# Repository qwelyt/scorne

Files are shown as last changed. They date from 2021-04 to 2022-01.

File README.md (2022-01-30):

# scorne
A corne with extra buttons. This is a scorned keyboard.

It is basically a corne, but with three extra buttons. This makes the layout work like a Lets Split (or half of a fourtwelve) but with a thumbcluster lite Corne. It only requires one MCU though.

Parts from https://github.com/MKSwe/OpenSCAD-utils are used in this project.

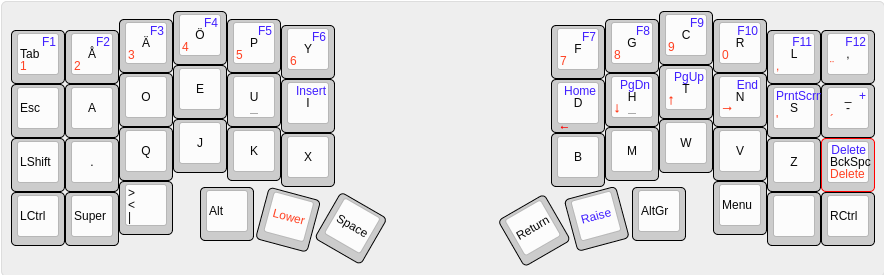
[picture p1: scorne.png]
Scorne keymap with Svorak layout


Scorne build pic
Scorne underside bulid pic

# LICENSE
The firmware is under GNU GPL 3.0.  
The hardware is under CERN-OHL-S.  
See the respective directories for this.

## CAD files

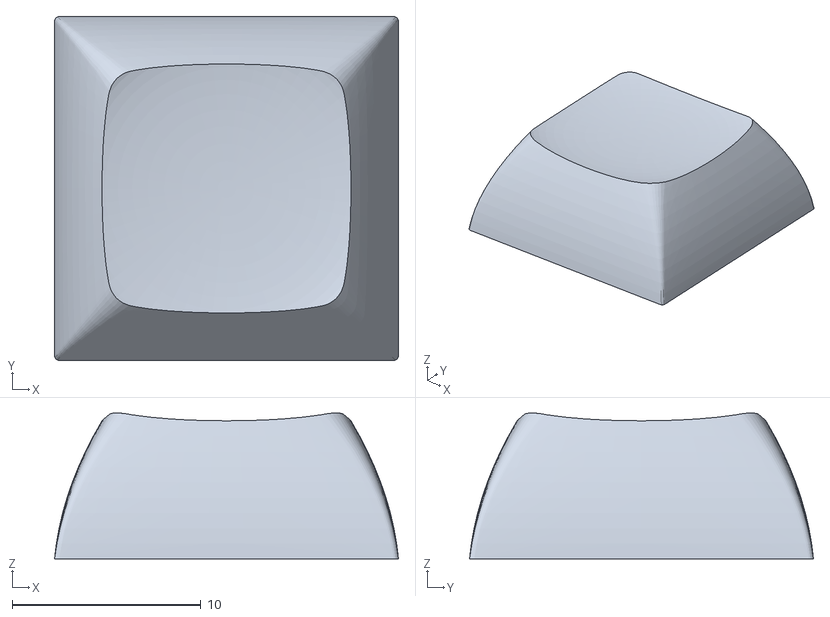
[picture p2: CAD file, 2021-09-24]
hardware/keycap_mx.stl
18.2 x 18.2 x 7.74

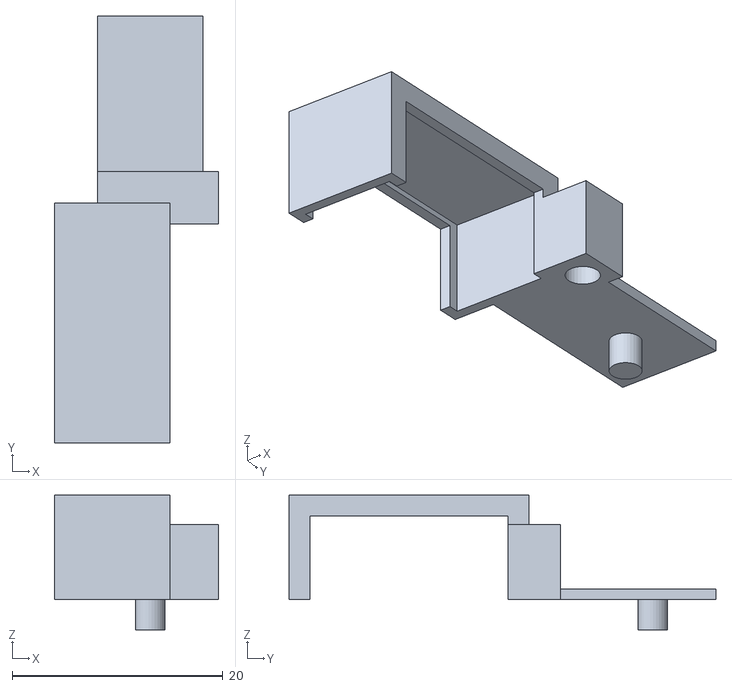
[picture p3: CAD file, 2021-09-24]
hardware/scorne-choc-IDC-right.stl
15.6 x 40.5 x 12.8

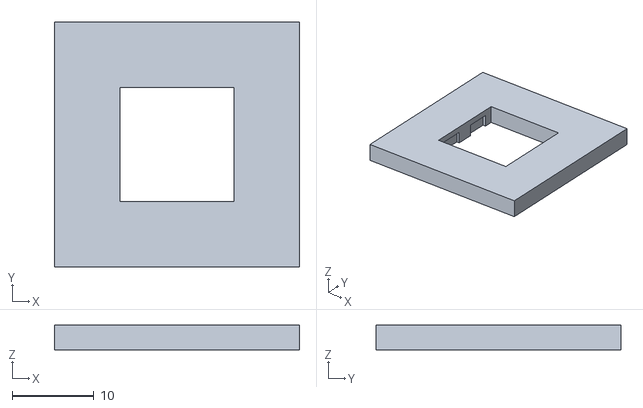
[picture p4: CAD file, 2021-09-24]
hardware/choc-cut-test.stl
30.0 x 30.0 x 3.00

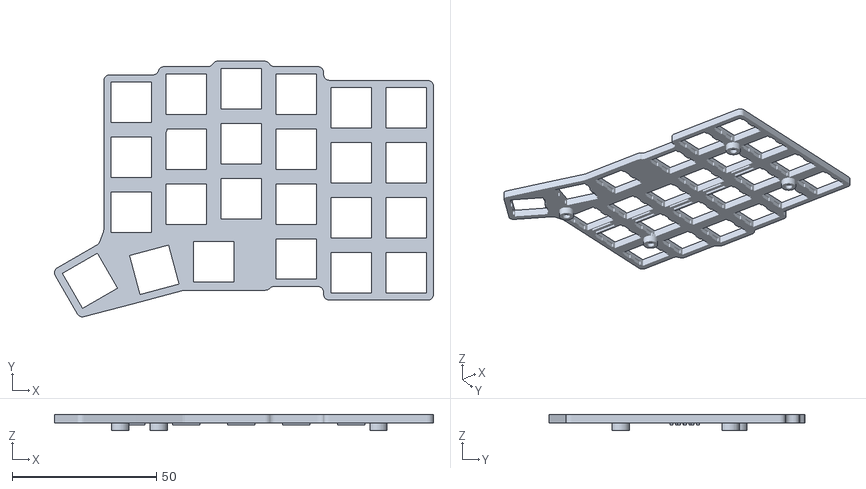
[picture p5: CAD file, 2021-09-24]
hardware/scorne-choc-top-right.stl
131.3 x 88.6 x 5.70

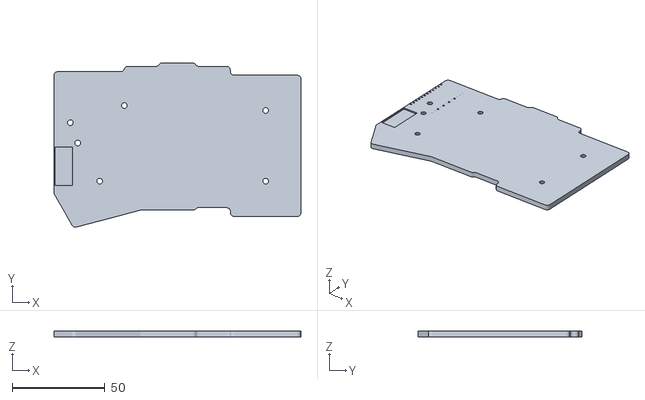
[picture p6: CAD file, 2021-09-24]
hardware/scorne-choc-bottom-right.stl
133.1 x 88.6 x 3.00

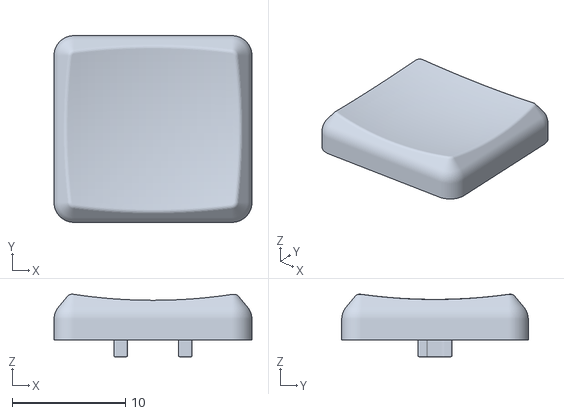
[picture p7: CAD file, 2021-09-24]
hardware/keycap_mbk.stl
17.5 x 16.5 x 5.52

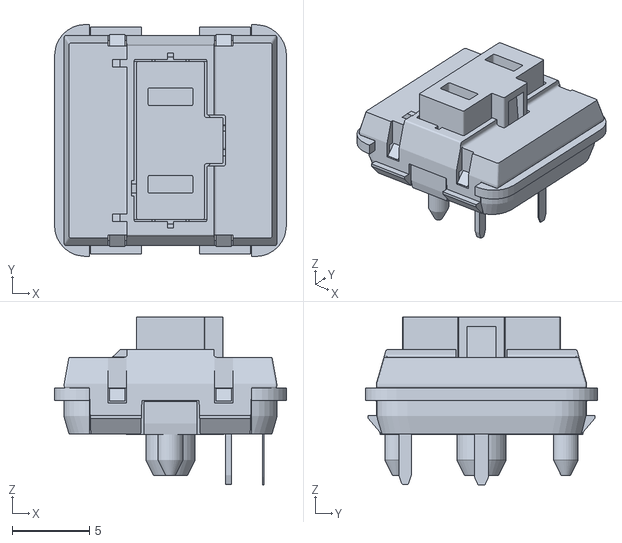
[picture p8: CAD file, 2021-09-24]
hardware/choc.stl
15.0 x 15.0 x 10.9

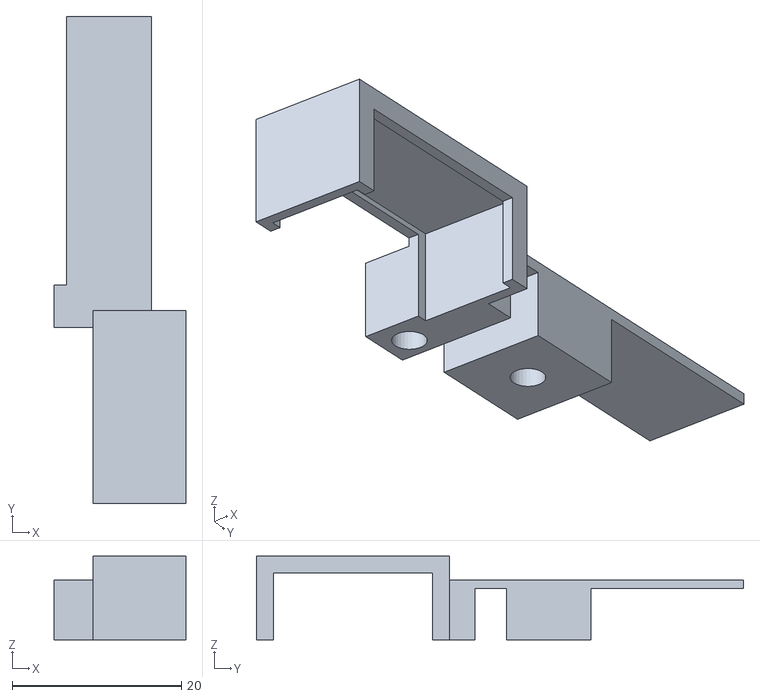
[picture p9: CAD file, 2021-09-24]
hardware/scorne-choc-IDC-left.stl
15.6 x 57.5 x 9.90

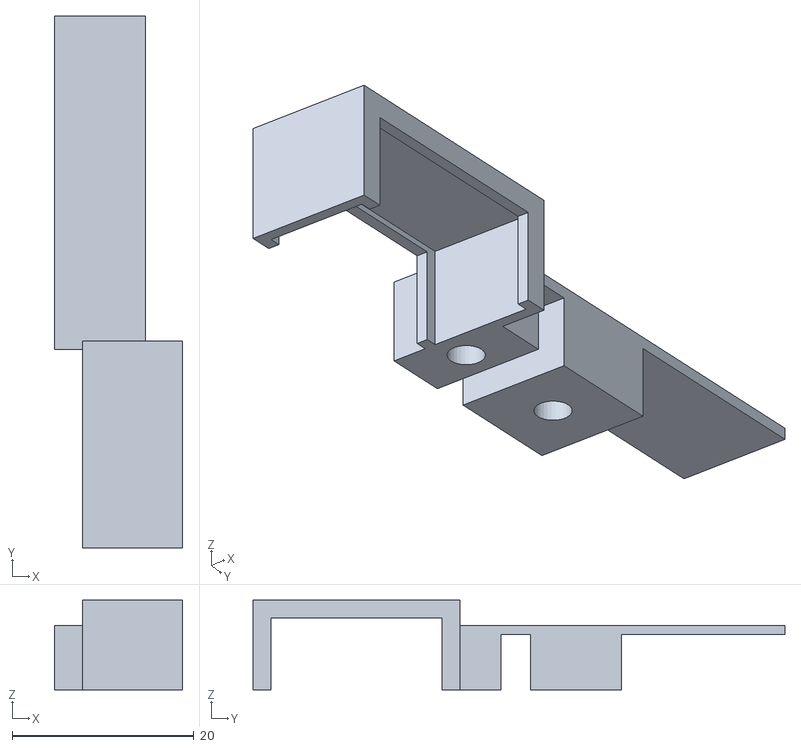
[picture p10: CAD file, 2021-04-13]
hardware/socket-IDC-holder.stl
14.1 x 58.6 x 9.90

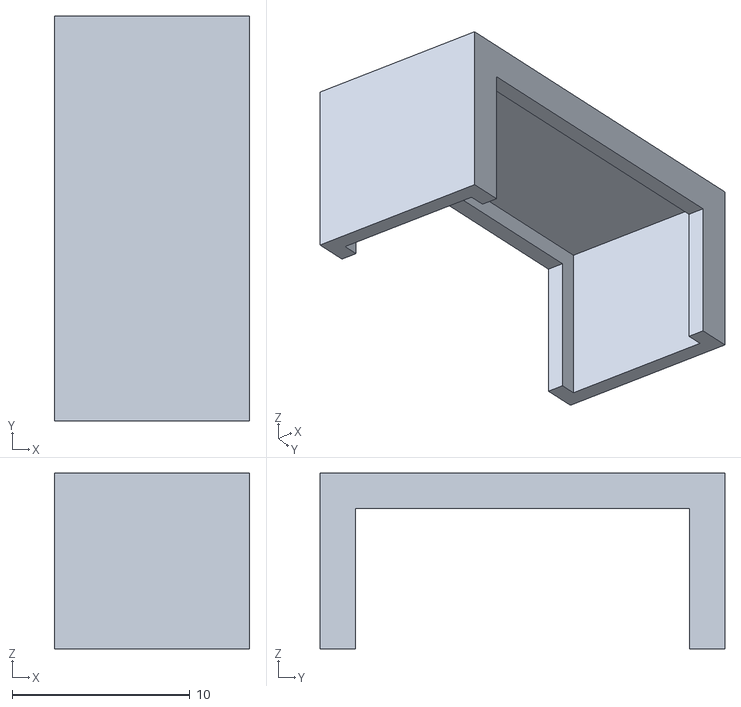
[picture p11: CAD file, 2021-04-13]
hardware/IDC-holder.stl
11.0 x 22.8 x 9.90

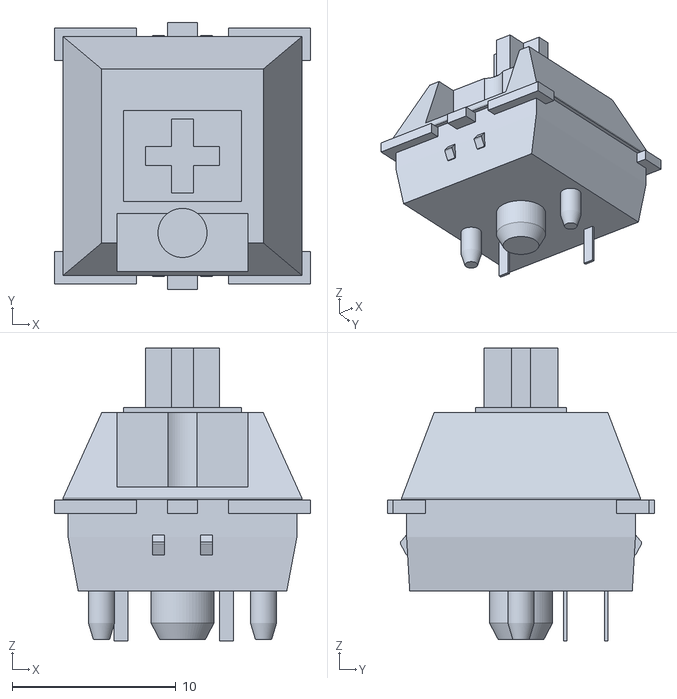
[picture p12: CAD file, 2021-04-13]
hardware/switch_mx.stl
15.6 x 16.3 x 17.9

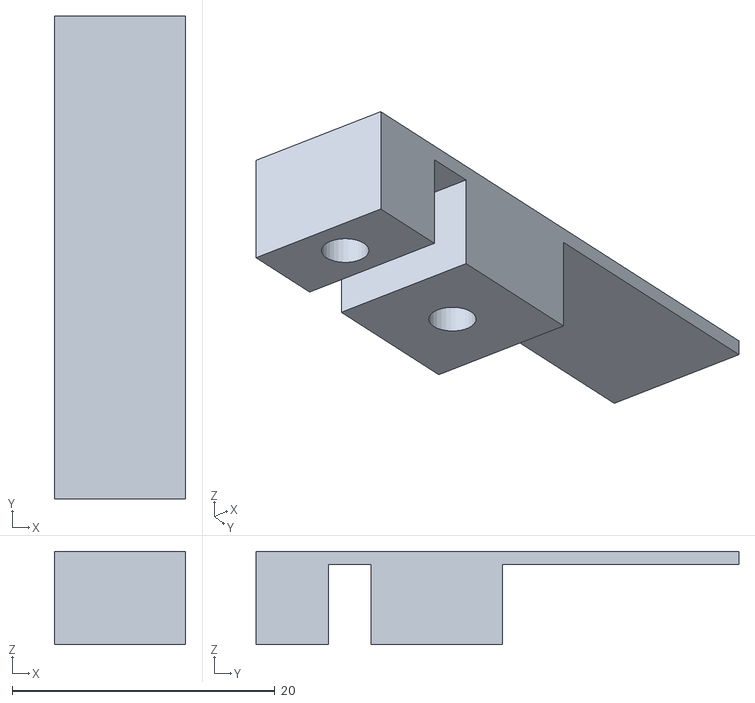
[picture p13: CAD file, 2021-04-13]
hardware/socketHolder.stl
10.00 x 36.8 x 7.10

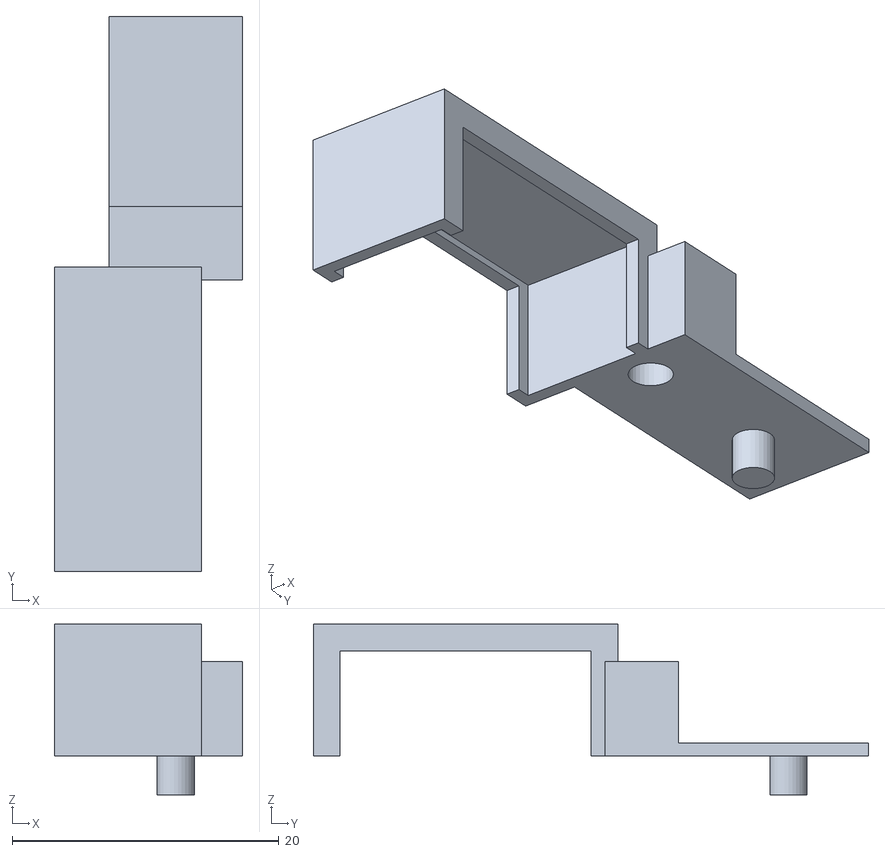
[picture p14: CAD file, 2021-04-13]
hardware/socket-IDC-holder_right.stl
14.1 x 41.6 x 12.8

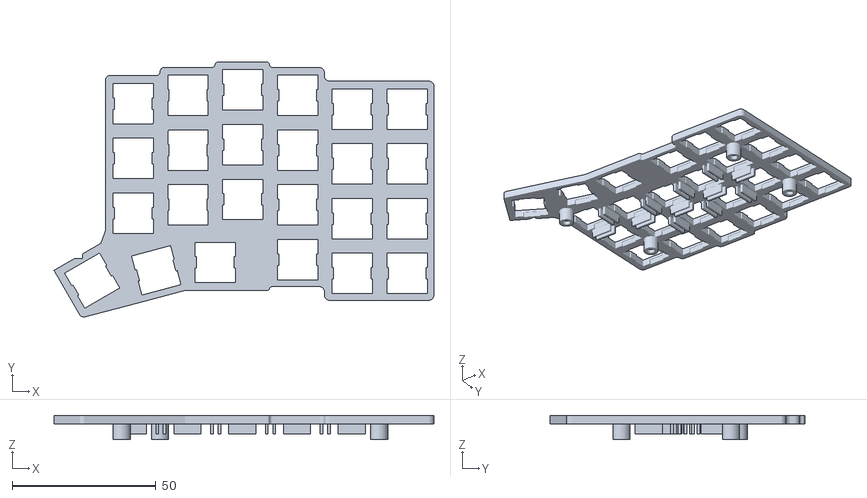
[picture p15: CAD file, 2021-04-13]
hardware/scorne_top_right.stl
132.1 x 88.6 x 8.50

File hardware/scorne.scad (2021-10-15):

showSwitchCut=true;
showSwitch=true;
showKeyCap=false;
showSpaceBox=false;
showScrews=false;
fullboard=false;
space=19.04;
switchType="MX"; // ["MX","choc"]

/*[Cherry MX settings]*/
cherryCutOutSize=13.9954;
cherrySize=14.58;

/*[Keeb]*/
keyCols = 14;
keyRows = 6;
keySpace = space-cherrySize;
edgeSpaceAddition = 3;
edgeSpace = (edgeSpaceAddition*2)-keySpace;
keyZ = -1;

$fn=30;
$fs=0.15;
mSize=3;
moduleZ = 3;
moduleX = size(keyCols);
moduleY = size(keyRows);
keyboardHeight=6.5; // 6.5 for MX, 3.7 for choc

/*[ Printer settings ]*/
showPrintBox=false;
printerSize=[140,140,140];

// mX: h=mX-1, d= X*(1+((1/3)*2))
function mNutH(m) = m-1;
function mNutD(m) = m*(1+((1/3)*2));
function mNutDHole(m) = mNutD(m)+2;
function mScrewheadH(m) = m-1;
function mScrewheadD(m) = m+3; // This is most probably not correct, but works for m3

          
function position(x,y,z) = [space*(x-1), space*(y-1), z];

function size(q) = (keySpace*q)
                        +cherrySize
                        *(q-1)
                        +cherrySize;
function Qsize(q) = (edgeSpace+edgeSpaceAddition)
              +(keySpace*q)
              +cherrySize
              *(q-1)
              +cherrySize;
          



module ooo(r=2){
  offset(r)offset(-r*2)offset(r)children();
}

// ---- Keyboard basics ----
module mxSwitchCut(x=cherryCutOutSize/1.5,y=cherryCutOutSize/1.5,z=0,rotateCap=false){
  capRotation = rotateCap ? 90 : 0;
  d=14.05;
  p=14.58/2+0.3;
  translate([x,y,z]){
    translate([0,0,-3.7])
    rotate([0,0,capRotation]){
      difference(){
        cube([d,d,10], center=true);
        translate([d*0.5,0,0])cube([1,4,12],center=true);
        translate([-d*0.5,0,0])cube([1,4,12],center=true);
      }


      translate([0,-(p-0.6),1.8]) rotate([-10,0,0]) cube([cherryCutOutSize/2,1,1.6],center=true);
      translate([0,-(p-0.469),-1.95]) cube([cherryCutOutSize/2,1,6.099],center=true);

      translate([0,(p-0.6),1.8]) rotate([10,0,0]) cube([cherryCutOutSize/2,1,1.6],center=true);
      translate([0,(p-0.469),-1.95]) cube([cherryCutOutSize/2,1,6.099],center=true);
    }
  }
}

module chocCut(){
  union(){
    cube([14,14,moduleZ*2],center=true);
    translate([0,14/4,-1])cube([15,4,moduleZ],center=true);
    translate([0,-14/4,-1])cube([15,4,moduleZ],center=true);
  }
}


module repeated (yStart, yEnd, xStart, xEnd, yStep=1, xStep=1){
  union(){
    for(y = [yStart:yStep:yEnd]){
      for(x = [xStart:xStep:xEnd]){
        translate(position(x,y,0)) children();
      }
    }
  }
}

module roundedCube(size=[1,1,1], center=false, r=0.5){
  tMin = r;
  txMax = size[0] - r;
  tyMax = size[1] - r;
  tzMax = size[2] - r;
  
  cent = center ? [-(txMax/2+r/2),-(tyMax/2+r/2),-(tzMax/2+r/2)] : [0,0,0];
  
  translate(cent)  
  hull(){
    translate([tMin,tMin,tMin])sphere(r=r);
    translate([tMin,tMin,tzMax])sphere(r=r);
    

    translate([txMax,tMin,tMin])sphere(r=r);
    translate([txMax,tMin,tzMax])sphere(r=r);
    
    
    translate([tMin,tyMax,tMin])sphere(r=r);
    translate([tMin,tyMax,tzMax])sphere(r=r);
    
    translate([txMax,tyMax,tMin])sphere(r=r);
    translate([txMax,tyMax,tzMax])sphere(r=r);
    
  }
}

///////////////////////////////
//  This
//////////////////////////////

module switchCut(){
  if(switchType == "MX"){
    mxSwitchCut();
  } else if(switchType == "choc") {
    translate([9.5,9.5,-moduleZ])chocCut();
  }
}
module switch(){
  if(switchType == "MX"){
    translate([9.5,9.5,15.15])import("switch_mx.stl");
  } else if(switchType == "choc") {
    translate([9.5,9.5,1.3])rotate([0,0,90])import("choc.stl");
  }
}

module keyCap(){
  if(switchType == "MX"){
    translate([9.5,9.5,7])import("keycap_mx.stl");
  } else if(switchType == "choc") {
//    translate([0,0,-2.0])
    translate([9.5,9.5,6.1])rotate([0,0,0])import("keycap_mbk.stl");
  }
}

module mounting(height=10){
  difference(){
    cylinder(d=mSize+3, h=height);
    translate([0,0,-1])cylinder(d=mSize, h=height+2);
  }
}

module keyPlacement(){
    repeated(0,3,1,2)children();
    repeated(0.25,3.25,3,3)children();
    repeated(1.35,3.35,4,4)children();
    repeated(1.25,3.25,5,5)children();
    repeated(1.1,3.1,6,6)children();
    
    translate([size(3.5),-size(0.8),0])children();
    translate([size(4.47),-size(0.8),0])rotate([0,0,-15])children();
    translate([size(5.57),-size(0.83),0])rotate([0,0,-30])children();
//  translate([size(5.57),-size(0.82),0])rotate([0,0,-30])children();
}

module holePlacement(){
  translate([size(1),size(0),0])children();
  translate([size(1),size(2),0])children();
  
//  translate([size(3.3),size(0),0])children();
//  translate([size(2.95),size(2.24),0])children();
  
  translate([size(5.7),size(0),0])children();
  translate([size(5),size(2.14),0])children();
}


module plateNoCuts(){
  union(){
    keyPlacement()square([size(1),size(1)]);
    translate([size(3),-size(0.82),0])square([size(3),size(1.2)]);
    translate([size(5.33),-size(0.82),0])
      rotate([0,0,20])
      square([size(1),size(1)]);
            
    translate([size(5.4005),-size(1.0495),0])
      rotate([0,0,-14.61])
      square([size(1.07),size(1)]);
  }
  
}
module cableGutter(h=10,rotate=false){
  hh = h > 6 ? h-2 : h-0.3; 
  echo(hh);
  if(rotate){
    union()translate([-0.5,-size(0.5),-(h/2)+1])rotate([0,0,90]){
      translate([0,1.1,0])cube([size(0.5),1,hh],center=true);
      translate([0,-1.5,0])cube([size(0.5),1,hh],center=true);
    }
  } else {
    union()translate([size(0.5),0,-(h/2)+1]){
      translate([0,1.1,0])cube([size(0.5),1,hh],center=true);
      translate([0,-1.5,0])cube([size(0.5),1,hh],center=true);
    }
  }
}

module plate(h=10){
  color([0.7,1,0.5]){
    difference(){
      translate([0,0,keyZ])linear_extrude(moduleZ)ooo()plateNoCuts();
      union(){
        translate([0,0,moduleZ])keyPlacement()switchCut();
      }
      holePlacement()translate([0,0,-h])cylinder(d=mSize,h=h);
    }
    
    translate([0,0,-h])holePlacement()mounting(h);
    
    
    
    translate([size(1),size(1),0])cableGutter(h);
    translate([size(2),size(1.25),0])cableGutter(h);
    translate([size(3),size(1.35),0])cableGutter(h);
    translate([size(4),size(1.25),0])cableGutter(h);
    translate([size(5),size(1.1),0])cableGutter(h);
  }
//  %holePlacement()translate([0,0,-h])cylinder(d=mSize,h=h);
  if(showSwitch){
    color([0.7,1,1])
    keyPlacement()switch();
  }
  if(showKeyCap){
    color([1,0.7,0.7])
    keyPlacement()keyCap();
  }
}

module bottom(){
  module socketHolder(){
    union(){
      cube([10,6,5]);
      translate([0,0,4])cube([10,1.3,3]);
      translate([0,6-1.3,4])cube([10,1.3,3]);
    }
  }
  module socketLegHoles(){
    for(i = [0:1:11]){
      translate([0,i*2.54,0])cylinder(d=1,h=3.2);
    }
  }
  
  module socketLegHole(){
    translate([0,0,0])socketLegHoles();
    translate([size(0.809),0,0])socketLegHoles();
  }
  
  module socketHolderHoles(){
    translate([-4,0.45,0])cylinder(d1=mScrewheadD(mSize),d2=mSize,h=moduleZ+0.2);
    
    translate([0,size(1)-7.6,0])cylinder(d1=mScrewheadD(mSize),d2=mSize,h=moduleZ+0.2);
   
  }
  
  difference(){
    translate([0,0,keyZ])linear_extrude(moduleZ)ooo()union(){
      plateNoCuts();
      translate([size(5.993),-size(0.454),0]){
        square([size(1),size(3.554)]);
      }
    }
    translate([0,0,-1.1])holePlacement()cylinder(d1=mScrewheadD(mSize),d2=mSize,h=moduleZ+0.2);
   
    
    translate([size(6.6208),size(-1),-moduleZ])
    rotate([0,0,-30])cube([size(1),size(3),moduleZ*2]);
    
    translate([size(6.53),size(1)+1.04,-1.1])socketHolderHoles();
    translate([size(6.125),size(1.265),1.55])socketLegHole();
    
    translate([size(6.47),-2.4,1.2])cube([9.5,20.8,10]);

  }
  

}

module socketHolder(blank=false){
  z=7.1;
  d=-1.75;
  module screwCube(){
    translate([-4,-18.25,d])cube([5,5,z],center=true);
    translate([0,-17.25,d])cube([10,3,z],center=true);
  }
  module cubeHole(){
          translate([-4,-18,-7])cylinder(d=mSize,h=6);
  }
  if(blank){
    difference(){
      union(){
        screwCube();
        translate([0,-9,-z+2.3])cube([10,16,1],center=true);
        translate([0,-7,-8.2])cylinder(d=mSize-0.2,h=moduleZ);
      }
      cubeHole();
    }    
  }else {
    difference(){
      union(){
        translate([0,-7,d])cube([10,10,z],center=true);
        screwCube();
        translate([0,0,1.3])cube([10,32,1],center=true);
      }
      translate([0,-7,-7])cylinder(d=mSize,h=6);
      cubeHole();
    }
  }
}

module IDCHolder(x=10,y=20,z=10,hollow=true){
  difference(){
    cube([x,y,z]);
    if(hollow){
      translate([-1,2,-1])cube([x+2,y-4,z-1]);
      translate([1,1,-1.5])cube([x-2,y-2,z]);
    }
  }
}

module screw(size=mSize,h=10){
  difference(){
    union(){
      cylinder(d1=mScrewheadD(size),d2=size,h=mScrewheadH(size));
      cylinder(d=size,h=h);
    }
    cube([1,10,1],center=true);
  }
}
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

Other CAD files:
hardware/scorne-choc-bottom-left.stl
hardware/scorne-choc-top-left.stl
hardware/scorne_bottom.stl
hardware/scorne_top.stl
hardware/IDC_2x5p.stl
hardware/pinHeader.stl
hardware/proMicro.stl
hardware/scorne.stl
hardware/scorne_bottom_right.stl
hardware/socket.stl

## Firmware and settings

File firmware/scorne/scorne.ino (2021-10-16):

#include "Keyboard.h"
#include "Key.h"

const byte numCols = 12;
const byte numRows = 4;

const byte layers = 4; // Normal, lower, raise, lower+raise
const byte scanRounds = 2;
const byte msDelayBetweenScans = 10;


int cols[numCols] = {2, 3, 4, 5, 6, 7, 8, 9, 10, 16, 14, 15};
int rows[numRows] = {A3, A2, A1, A0};


typedef struct {
  byte row;
  byte col;
  byte val;
} ModPosition;

const ModPosition lower = {3, 4, 1};
const ModPosition raise = {3, 7, 2};
const byte numModifiers = 2;

ModPosition modifiers[numModifiers] = {lower, raise};

const byte keyLimit = 6;
typedef struct {
  byte meta;
  byte keys[keyLimit];
} KeyBuffer;


byte keys[layers][numRows][numCols] = {
  // 0 Normal
  {
    {   Key::TAB    , Key::Q      , Key::W         , Key::E     , Key::R     , Key::T      , Key::Y       , Key::U       , Key::I       , Key::O       , Key::P         , Key::OBRAKET   }
    , { Key::ESC    , Key::A      , Key::S         , Key::D     , Key::F     , Key::G      , Key::H       , Key::J       , Key::K       , Key::L       , Key::COLON     , Key::QUOTE     }
    , { Key::L_SHFT , Key::Z      , Key::X         , Key::C     , Key::V     , Key::B      , Key::N       , Key::M       , Key::COMMA   , Key::DOT     , Key::SLASH     , Key::BACKSPACE }
    , { Key::L_CTRL , Key::L_SUPR , Key::BS_N_PIPE , Key::L_ALT , MOD::Lower , Key::SPACE  , Key::RETURN  , MOD::Raise   , Key::R_ALT   , Key::MENU    , Key::R_SUPR    , Key::R_CTRL    }
  }
  // 1 Lower
  , {
    {   Key::K1     , Key::K2     , Key::K3        , Key::K4    , Key::K5    , Key::K6     , Key::K7      , Key::K8      , Key::K9      , Key::K0      , Key::OBRAKET   , Key::CBRAKET   }
    , { Key::ESC    , Key::NONE   , Key::NONE      , Key::NONE  , Key::NONE  , Key::NONE   , Key::ARROW_L , Key::ARROW_D , Key::ARROW_U , Key::ARROW_R , Key::TILDE     , Key::EQUAL     }
    , { Key::L_SHFT , Key::NONE   , Key::NONE      , Key::NONE  , Key::NONE  , Key::NONE   , Key::NONE    , Key::NONE    , Key::NONE    , Key::NONE    , Key::NONE      , Key::DELETE    }
    , { Key::L_CTRL , Key::L_SUPR , Key::GACC      , Key::L_ALT , MOD::Lower , Key::SPACE  , Key::RETURN  , MOD::Raise   , Key::R_ALT   , Key::MENU    , Key::R_SUPR    , Key::R_CTRL    }
  }
  // 2 Raise
  , {
    {   Key::F1     , Key::F2     , Key::F3        , Key::F4    , Key::F5    , Key::F6     , Key::F7      , Key::F8      , Key::F9      , Key::F10     , Key::F11       , Key::F12       }
    , { Key::ESC    , Key::NONE   , Key::NONE      , Key::NONE  , Key::NONE  , Key::INSERT , Key::HOME    , Key::PGDWN   , Key::PGUP    , Key::END     , Key::PRNT_SCRN , Key::DASH      }
    , { Key::L_SHFT , Key::NONE   , Key::NONE      , Key::NONE  , Key::NONE  , Key::NONE   , Key::NONE    , Key::NONE    , Key::NONE    , Key::NONE    , Key::NONE      , Key::DELETE    }
    , { Key::L_CTRL , Key::L_SUPR , Key::NONE      , Key::L_ALT , MOD::Lower , Key::SPACE  , Key::RETURN  , MOD::Raise   , Key::R_ALT   , Key::MENU    , Key::R_SUPR    , Key::R_CTRL    }
  }
  // 3 Both
  , {
    {   Key::NONE   , Key::NONE   , Key::NONE      , Key::NONE  , Key::NONE  , Key::NONE   , Key::NONE    , Key::NONE    , Key::NONE    , Key::NONE    , Key::NONE      , Key::NONE      }
    , { Key::ESC    , Key::NONE   , Key::NONE      , Key::NONE  , Key::NONE  , Key::NONE   , Key::MUTE    , Key::VOL_DN  , Key::VOL_UP  , Key::NONE    , Key::NONE      , Key::NONE      }
    , { Key::L_SHFT , Key::NONE   , Key::NONE      , Key::NONE  , Key::NONE  , Key::NONE   , Key::PLAY    , Key::PREV    , Key::NEXT    , Key::NONE    , Key::NONE      , Key::NONE      }
    , { Key::L_CTRL , Key::L_SUPR , Key::NONE      , Key::L_ALT , MOD::Lower , Key::SPACE  , Key::RETURN  , MOD::Raise   , Key::R_ALT   , Key::MENU    , Key::R_SUPR    , Key::R_CTRL    }
  }
};


bool pressed[scanRounds][numRows][numCols] = {};
bool lastState[numRows][numCols] = {};
bool state[numRows][numCols] = {};
KeyBuffer lastKeyBuffer;
KeyBuffer keyBuffer;

/*********************
****    BEGIN!    ****
*********************/

void setup() {
  for (byte b = 0; b < numRows; ++b) {
    setupRow(rows[b]);
  }

  for (byte b = 0; b < numCols; ++b) {
    setupCol(cols[b]);
  }
  initKeyboard();
}

void setupCol(byte pin) {
  pinMode(pin, INPUT_PULLUP);
}

void setupRow(byte pin) {
  pinMode(pin, OUTPUT);
  digitalWrite(pin, HIGH);
}

///////////////////////////


void loop() {
  scan(scanRounds, numRows, numCols, rows, pressed[0][0], msDelayBetweenScans);
  readCurrentState(scanRounds, numRows, numCols, pressed[0][0], state[0]);

  if (stateChanged(numRows, numCols, state[0], lastState[0])) {
    sendState(numRows, numCols, numModifiers, state[0], lastState[0], keys[0][0], modifiers);
    saveState(state[0], lastState[0], numRows, numCols);
  }
}

//////////
//  Scan
//////////

void scan(byte scanRounds, byte numRows, byte numCols, int *rows, bool *pressed, int msDelayBetweenScans) {
  for (byte scanRound = 0; scanRound < scanRounds; ++scanRound) {
    debounce(pressed, rows, scanRound, numRows, numCols);
    delay(msDelayBetweenScans);
  }
}

void debounce(bool *pressed, int *rows, byte scanRound, byte numRows, byte numCols) {
  for (byte row = 0; row < numRows; ++row) {
    digitalWrite(rows[row], LOW);
    for (byte col = 0; col < numCols; ++col) {
      pressed[(scanRound * numRows + row)*numCols + col] = readPin(cols[col]);
    }
    digitalWrite(rows[row], HIGH);
  }
}

bool readPin(byte pin) {
  if (!digitalRead(pin)) {
    return true;
  }
  return false;
}


//////////
// State
//////////

void readCurrentState(byte scanRounds, byte numRows, byte numCols, bool *pressed, bool *state) {
  for (byte row = 0; row < numRows; ++row) {
    for (byte col = 0; col < numCols; ++col) {
      bool isPressed = true;
      for (byte scanRound = 0; scanRound < scanRounds; ++scanRound) {
        isPressed = isPressed && pressed[(scanRound * numRows + row) * numCols + col];
      }
      state[row * numCols + col] = isPressed;
    }
  }
}

bool stateChanged(byte numRows, byte numCols, bool *currentState, bool *lastState) {
  for (byte row = 0; row < numRows; ++row) {
    for (byte col = 0; col < numCols; ++col) {
      if (lastState[row * numCols + col] != currentState[row * numCols + col]) {
        return true;
      }
    }
  }
  return false;
}

void saveState(bool *currentState, bool *lastState, byte numRows, byte numCols) {
  for (byte row = 0; row < numRows; ++row) {
    for (byte col = 0; col < numCols; ++col) {
      lastState[row * numCols + col] = currentState[row * numCols + col];
    }
  }
}


////////////
//// Key buffer
////////////

void sendState(byte numRows, byte numCols, byte numModifiers, bool *state, bool *lastState, byte *keys, ModPosition *modifiers ) {
  byte layer = checkLayer(state, modifiers, numModifiers, numRows, numCols);

  byte keyLimit = 6;
  byte keyIndex = 0;

 // printState(state, numCols, numRows);

  for (byte row = 0; row < numRows; ++row) {
    for (byte col = 0; col < numCols; ++col) {
      if (state[row * numCols + col] == true) {
        if(isModifier(row, col, modifiers, numModifiers)){
          continue;
        }
        byte key = 0;
        for (byte l = layer; l >= 0 && key == 0; --l) {
          key = keys[(l * numRows + row ) * numCols + col];
        }
        byte metaVal = metaValue(key);
        keyBuffer.meta |= metaVal;
        if (metaVal == 0) {
          keyBuffer.keys[keyIndex++] = key;
        }
        if (keyIndex == keyLimit) {
          sendBuffer(&keyBuffer, keyLimit);
          saveKeyBuffer(&keyBuffer, &lastKeyBuffer, keyLimit);
          keyIndex = resetBuffer(&keyBuffer, keyLimit);
        }
      }
    }
  }
 // printKeyBuf(&keyBuffer, keyLimit);
 // printKeyBuf(&lastKeyBuffer, keyLimit);


  if (keyIndex != 0 || keyBufferChanged(&keyBuffer, &lastKeyBuffer, keyLimit)) {
    sendBuffer(&keyBuffer, keyLimit);
    saveKeyBuffer(&keyBuffer, &lastKeyBuffer, keyLimit);
    keyIndex = resetBuffer(&keyBuffer, keyLimit);
  }
  if(stateChanged(numRows, numCols, state, lastState)){
    keyIndex = resetBuffer(&keyBuffer, keyLimit);
  }
   // printKeyBuf(&lastKeyBuffer, keyLimit);
}

bool keyBufferChanged(KeyBuffer *currentBuffer, KeyBuffer *lastBuffer, byte keyLimit) {
  if(currentBuffer->meta != lastBuffer->meta) {
    return true;
  }
  for(byte b=0; b<keyLimit; ++b){
    if(currentBuffer->keys[b] != lastBuffer->keys[b]){
      return true;
    }
  }
  return false;
}

void saveKeyBuffer(KeyBuffer *current, KeyBuffer *saveTo, byte keyLimit) {
  saveTo->meta = current->meta;
  for(byte b=0; b<keyLimit; ++b){
    saveTo->keys[b] = current->keys[b];
  }
}

byte checkLayer(bool *state, ModPosition *modifiers, byte numModifiers, byte numRows, byte numCols) {
  byte layer = 0;
  for (byte modifier = 0; modifier < numModifiers; ++modifier) {
    ModPosition mod = modifiers[modifier];
    layer += state[mod.row * numCols + mod.col] == true ? mod.val : 0;
  }
  return layer;
}

bool isModifier(byte row, byte col, ModPosition *modifiers, byte numModifiers) {
  for (byte modifier = 0; modifier < numModifiers; ++modifier) {
    ModPosition mod = modifiers[modifier];
    if (mod.row == row && mod.col == col) {
      return true;
    }
  }
  return false;
}

bool isKeyWithValue(byte key) {
  return key != Key::NONE;
}


byte metaValue(byte key) {
  switch (key) {
    case Key::L_CTRL:
      return Mod::LCTRL;
    case Key::L_SHFT:
      return Mod::LSHFT;
    case Key::L_ALT:
      return Mod::LALT;
    case Key::L_SUPR:
      return Mod::LSUPR;
    case Key::R_CTRL:
      return Mod::RCTRL;
    case Key::R_SHFT:
      return Mod::RSHFT;
    case Key::R_ALT:
      return Mod::RALT;
    case Key::R_SUPR:
      return Mod::RSUPR;
    default:
      return 0;
  }
}

byte resetBuffer(KeyBuffer *keyBuf, byte keyLimit) {
  for (byte b = 0; b < keyLimit; ++b) {
    keyBuf->keys[b] = Key::NONE;
  }
  keyBuf->meta = 0;
  return 0;
}

void sendBuffer(KeyBuffer *keyBuf, byte keyLimit){
  //printKeyBuf(keyBuf, keyLimit);
  sendKeyBuffer(keyBuf->meta, keyBuf->keys, keyLimit);
}

////////////
//// Debug
////////////

void printState(bool *state, byte numCols, byte numRows) {
  Serial.println("State");
  Serial.print(" ");
  for (int j = 0; j < numCols; ++j) {
    Serial.print(" ");
    Serial.print(j);
  }
  for (int row = 0; row < numRows ; ++row) {
    Serial.println();
    Serial.print(row);
    for (int col = 0; col < numCols; ++col) {
      Serial.print(" ");
      Serial.print(state[row * numCols + col]);
    }
  }
  Serial.println();
}

void printKeyBuf(KeyBuffer *keyBuf, byte keyLimit) {
  Serial.print("keyBuf: ");
  Serial.print(" ");
  Serial.print(keyBuf->meta);
  for (byte b = 0; b < keyLimit; ++b) {
    Serial.print(" ");
    Serial.print(keyBuf->keys[b]);
  }
  Serial.println();
}

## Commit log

2021-03-24 Add keyboard build
    [pro-micro.stl, pro-micro_wpins.stl, scorne.scad]
2021-03-24 Organise and add start of MCU socket
    [pro-micro.stl, pro-micro_wpins.stl, scorne.scad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]
2021-03-24 Add socket lib
    [socket.scad, socket24.stl]
2021-03-24 Make the scad file easier to customize
    [socket.scad]
2021-03-25 Add almost complete keyboard
    The only thing missing is the IDC connector. The thing that will connect
    the two halves together. As I don't have that part yet I don't know what
    it looks like and how I should mount it properly.
    pinHeader, socket and pro-micro are from https://github.com/MKSwe/OpenSCAD-utils
    [pinHeader.stl, pro-micro.stl, pro-micro_wpins.stl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]
2021-03-25 Add full build
    With pro micro and socket in place just to show how it will look with
    those in place
    [scorne.stl]
2021-04-13 Finished board
    [IDC-holder.stl, IDC_2x5p.stl, scorne.scad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]
2021-04-14 Render of whole keyboard
    [scorne.scad]
2021-04-27 Update firmware to not blink
    Got tired of the code sending empty keybuffers when you pressed a layer
    key. They should not trigger any sending of keys at all. They are
    internal things to the keyboard and should not trigger us to send a
    datagram to the host.
    This introduced a "fun" bug in the beginning where it would not clear
    keys if you first help SHIFT, pressed a layer, released SHIFT, released
    layer. It would think that SHIFT was still pressed. This was due to the
    new way we check if we should send a datagram. We don't check if the
    state has changed anymore for this, we check if the keybuffer has
    changed. Solved it by actually checking the state later to see if the
    keybuffer should be res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
    [scorne.ino]
2021-09-24 Rework and add support for chocs
    You can choose to use chocs instead of MX switches. Reworked quite a bit
    to make the chocs work with how low I wanted the keyboard. With the old
    design the choc-caps would hit the IDC-port. With the rework it should
    not hit anything.
    [choc-cut-test.stl, choc.stl, keycap_mbk.stl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]
2021-10-14 Expand screw head hole .5mm
    [scorne.scad]
2021-10-15 Cable gutter fix
    [scorne.scad]
